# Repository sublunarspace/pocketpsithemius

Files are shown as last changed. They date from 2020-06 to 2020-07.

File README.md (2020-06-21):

# Pocket Psithemius

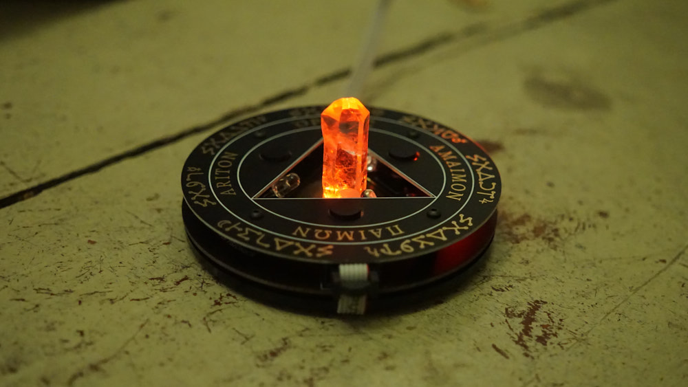
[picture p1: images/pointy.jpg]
Psithemius


The Psithemius is a psionic device for spirit conjuration and magical manifestation.

Its basic architecture consists of printed circuit boards hosting concentric circles with magical names and symbols and a triangle with a spiral shaped transmitter in its center. The design is based on a system attributed to the German abbot and polymath Johannes Trithemius who lived around the end of the 15th century and developed methods for communing with transdimensional entities.

For the Psithemius device to work properly, a quartz crystal is needed. The device emits light and an electromagnetic field around and into this quartz crystal set in the center of the triangle that acts as a focal point and spirit medium.

The Psithemius device utilizes principles from Psionics to detect and electrically amplify intent in the form of magical sigils or radionic rates sent to it. The goal is to charge the crystal with energies resonating with the nature of an entity and act as a beacon of condensed intent to attract them to the ritual space.

## Get the Psithemius

You can [purchase a Pocket Psithemius directly from Sublunar Psionics](mailto:info@sublunar.space). It comes in three different versions. All versions come with a USB power cable and a small carry bag.

* Fully assembled device (EUR 99.00)
* DIY kit incl. PCBs and all components (EUR 69.00)
* PCBs only - without components (EUR 49.00)

[Operator Manual](MANUAL.md)

[Assembly Instructions](hardware/ASSEMBLY.md)

[BOM List of Components](hardware/BOM.csv) / [PDF](hardware/BOM.pdf)

[Component Images](hardware/parts_preview.pdf)

## Code the Psithemius

Modify the firmware that runs the Psithemius or write your own from scratch. It's all fully Arduino compatible.

[Arduino IDE Firmware](firmware/)

## Fork the Psithemius

You can download the KiCAD project files (schematic, circuit board design, gerber files) and manufacture your own Psithemius or modify it

[KiCAD Files](hardware/)

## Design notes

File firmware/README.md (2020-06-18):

# Pocket Psithemius

Firmware for the Pocket Psithemius device.

## Installation

* Set up an Arduino as ISP programmer following [this tutorial](https://www.arduino.cc/en/Tutorial/ArduinoISP) or use any other ICSP compatible programmer.
* The firmware depends on the [OneButton library](https://github.com/mathertel/OneButton) which you need to install with the IDE's Library Manager
* Connect the Pocket Psithemius via ICSP to the programmer.

### IDE Tools Settings

* Board: Attiny24/44/84
* Chip: Attiny84
* Clock: 8MHz (internal)
* B.O.D. Level: B.O.D. Disabled
* Save EEPROM: EEPROM retained
* Pin Mapping: clockwise
* LTO: Enabled
* millis()/micros(): Enabled

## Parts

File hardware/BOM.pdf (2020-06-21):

Reference | Quantity Value | Description | Manufacturer | Part Number | Digikey Number | Mouser Number
C1 | 1 | 1uF | Capacitor | Vishay | K105Z20Y5VF5TH5 BC1168CT-ND | 594-K105Z20Y5VF5TH5
C2, C5, C10 | 3 | 0.1uF | Capacitor | Vishay | K104K15X7RF5TH5 BC1101CT-ND | 594-K104K15X7RF5TH5
C3 | 1 | 0.1uF/35V | Pol. Capacitor | Nishicon | UMA1H0R1MCD2TP 493-10420-3-ND | N/A
C4 | 1 | 10uF/10V | Pol. Capacitor | Vishay | USV1C100MFD | 493-16020-ND | 647-USV1C100MFD1TE
C6, C11 | 2 | 220uF/16V | Pol. Capacitor | Nishicon | USR1C221MDD | 493-15996-ND | 647-USR1C221MDD
D1 | 1 | LED_RGBA | RGB LED | Würth Elektronik | 156125M173000 | 732-11426-1-ND | 710-156125M173000
D2, D3, D4 | 3 | UV | UV LED | Nichia | VAOL-5GUV8T4 | VAOL-5GUV8T4-ND 593-VAOL5GUV8T4
H1, H2, H3, H4 | 4 | M2.5/9mm | Distance Bolt | Würth Elektronik | 960090021 | 732-12693-ND | N/A
H1, H2, H3, H4 | 4 | M2.5/7mm | Distance Bolt | Würth Elektronik | 960070021 | 732-12683-ND | N/A
H1, H2, H3, H4 | 4 | M2.5/25mm | Screw | N/A | 10.9-7380-M2.5x20 | N/A | N/A
H1, H2, H3, H4 | 4 | M2.5 | Washer | N/A | ST-M2.5-125 | N/A | N/A
H1, H2, H3, H4 | 4 | M2.5 | Nut | N/A | ST-M2.5-934 | N/A | N/A
J1 | 1 | 3.5mm | Audio Mini Jack | CUI Devices | SJ1-3523N | CP1-3523N-ND | 490-SJ1-3523N
J2 | 1 | PJ-051AH | Barrel Jack | CUI Devices | PJ-051AH | CP-051AH-ND | 490-PJ-051AH
J3 | 1 | 7761 | M2.5 / Earth | Keystone Electronics | 7761 | 36-7761-ND | 534-7761
J4 | 1 | AVR-ISP-6 | Flat Cable Socket Würth Elektronik | 61200621721 | 732-5404-ND | 710-61200621721
J5 | 1 | BAT | Battery Socket | JST | S4B-PH-K-S(LF)(SN) 455-1721-ND | N/A
R1, R2, R3, R4, R7 | 5 | 10K | Resistor | Stackpole Electronics CF18JT10K0 | CF18JT10K0CT-ND N/A
R5 | 1 | 10 | Resistor | Stackpole Electronics CF18JT10R0 | CF18JT10R0CT-ND N/A
R6, R11, R15 | 3 | 180 | Resistor | Stackpole Electronics CF18JT180R | CF18JT180RCT-ND N/A
R8, R9, R10 | 3 | 680 | Resistor | Stackpole Electronics CF18JT680R | CF18JT680RCT-ND N/A
R12, R13, R14 | 3 | 330 | Resistor | Stackpole Electronics CF18JT330R | CF18JT330RCT-ND N/A
R16 | 1 | 4 | Resistor | Stackpole Electronics WW1AFT4R00 | WW1AFT4R00-ND | N/A
SW1, SW2, SW3 | 3 | B3F-4050 | Switch | Omron | B3F-4050 | SW413-ND | 653-B3F-4050
SW1, SW2, SW3 | 3 | | Switch Cap | Omron | B32-1610 | SW847-ND | 653-B32-1610
SW4 | 1 | JS202011AQN Switch | C & K | JS202011AQN | 401-2000-ND | 611-JS202011AQN
U1 | 1 | ATtiny84A-PU Microcontroller | Microchip Technology ATTINY84-20PU | ATTINY84-20PU-ND 556-ATTINY84-20PU
U2 | 1 | TLP222A | Optical Relay | Toshiba | TLP222A-2(F) | TLP222A-2F-ND | 757-TLP222A-2(F)
U3 | 1 | TLP4227GF | Optical Relay | Toshiba | TLP4227GF | TLP4227GF-ND | 757-TLP4227G(F)
U4 | 1 | LM386 | Op-Amp | Texas Instruments | LM386MX-1/NOPB | 296-44414-5-ND | 926-LM386MX-1/NOPB
VR1 | 1 | 3352T-1-103LF Var. Resistor | Bourns | 3352T-1-103LF | 3352T-103LF-ND | 652-3352T-1-103LF

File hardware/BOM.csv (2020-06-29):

Reference | Quantity | Value | Description | Datasheet | Manufacturer | Part Number | Digikey Number | Mouser Number
C1 | 1 | 1uF | Capacitor | http://www.vishay.com/docs/45171/kseries.pdf | Vishay | K105Z20Y5VF5TH5 | BC1168CT-ND | 594-K105Z20Y5VF5TH5
C2, C5, C10 | 3 | 0.1uF | Capacitor | http://www.vishay.com/docs/45171/kseries.pdf | Vishay | K104K15X7RF5TH5 | BC1101CT-ND | 594-K104K15X7RF5TH5
C3 | 1 | 0.1uF/35V | Pol. Capacitor | https://www.nichicon.co.jp/english/products/pdfs/e-uma.pdf | Nishicon | UMA1H0R1MCD2TP | 493-10420-3-ND | N/A
C4 | 1 | 10uF/10V | Pol. Capacitor | http://nichicon-us.com/english/products/pdfs/e-usv.pdf | Vishay | USV1C100MFD | 493-16020-ND | 647-USV1C100MFD1TE
C6, C11 | 2 | 220uF/16V | Pol. Capacitor | http://nichicon-us.com/english/products/pdfs/e-usa_usr.pdf | Nishicon | USR1C221MDD | 493-15996-ND | 647-USR1C221MDD
D1 | 1 | LED_RGBA | RGB LED | https://katalog.we-online.de/led/datasheet/156125M173000.pdf | Würth Elektronik | 156125M173000 | 732-11426-1-ND | 710-156125M173000
D2, D3, D4 | 3 | UV | UV LED | http://static.vcclite.com/pdf/VAOL-5GUV8T4-LED-5mm-UV.pdf | Nichia | VAOL-5GUV8T4 | VAOL-5GUV8T4-ND | 593-VAOL5GUV8T4
H1, H2, H3, H4 | 4 | M2.5/9mm | Distance Bolt | https://katalog.we-online.de/em/datasheet/960xxxxxx.pdf | Würth Elektronik | 960090021 | 732-12693-ND | N/A
H1, H2, H3, H4 | 4 | M2.5/7mm | Distance Bolt | https://katalog.we-online.de/em/datasheet/960xxxxxx.pdf | Würth Elektronik | 960070021 | 732-12683-ND | N/A
H1, H2, H3, H4 | 4 | M2.5/25mm | Screw | N/A | N/A | 10.9-7380-M2.5x20 | N/A | N/A
H1, H2, H3, H4 | 4 | M2.5 | Washer | N/A | N/A | ST-M2.5-125 | N/A | N/A
H1, H2, H3, H4 | 4 | M2.5 | Nut | N/A | N/A | ST-M2.5-934 | N/A | N/A
J1 | 1 | 3.5mm | Audio Mini Jack | https://www.cuidevices.com/product/resource/digikeypdf/sj1-352xn.pdf | CUI Devices | SJ1-3523N | CP1-3523N-ND | 490-SJ1-3523N
J2 | 1 | PJ-051AH | Barrel Jack | https://www.cuidevices.com/product/resource/pj-051ah.pdf | CUI Devices | PJ-051AH | CP-051AH-ND | 490-PJ-051AH
J3 | 1 | 7761 | M2.5 / Earth | http://keyelco.com/userAssets/file/M65p69.pdf | Keystone Electronics | 7761 | 36-7761-ND | 534-7761
J4 | 1 | AVR-ISP-6 | Flat Cable Socket | https://katalog.we-online.de/em/datasheet/6120xx21721.pdf | Würth Elektronik | 61200621721 | 732-5404-ND | 710-61200621721
J5 | 1 | BAT | Battery Socket | http://www.jst-mfg.com/product/pdf/eng/ePH.pdf | JST | S4B-PH-K-S(LF)(SN) | 455-1721-ND | N/A
R1, R2, R3, R4, R7 | 5 | 10K | Resistor | https://www.seielect.com/catalog/sei-cf_cfm.pdf | Stackpole Electronics | CF18JT10K0 | CF18JT10K0CT-ND | N/A
R5 | 1 | 10 | Resistor | https://www.seielect.com/catalog/sei-cf_cfm.pdf | Stackpole Electronics | CF18JT10R0 | CF18JT10R0CT-ND | N/A
R6, R11, R15 | 3 | 180 | Resistor | https://www.seielect.com/catalog/sei-cf_cfm.pdf | Stackpole Electronics | CF18JT180R | CF18JT180RCT-ND | N/A
R8, R9, R10 | 3 | 680 | Resistor | https://www.seielect.com/catalog/sei-cf_cfm.pdf | Stackpole Electronics | CF18JT680R | CF18JT680RCT-ND | N/A
R12, R13, R14 | 3 | 330 | Resistor | https://www.seielect.com/catalog/sei-cf_cfm.pdf | Stackpole Electronics | CF18JT330R | CF18JT330RCT-ND | N/A
R16 | 1 | 4 | Resistor | https://www.seielect.com/catalog/sei-cf_cfm.pdf | Stackpole Electronics | WW1AFT4R00 | WW1AFT4R00-ND | N/A
SW1, SW2, SW3 | 3 | B3F-4050 | Switch | https://omronfs.omron.com/en_US/ecb/products/pdf/en-b3f.pdf | Omron | B3F-4050 | SW413-ND | 653-B3F-4050
SW1, SW2, SW3 | 3 |  | Switch Cap | https://omronfs.omron.com/en_US/ecb/products/pdf/en-b32.pdf | Omron | B32-1610 | SW847-ND | 653-B32-1610
S1 | 1 | JS202011AQN | Switch | https://www.ckswitches.com/media/1422/js.pdf | C & K | JS202011AQN | 401-2000-ND | 611-JS202011AQN
U1 | 1 | ATtiny84A-PU | Microcontroller | http://ww1.microchip.com/downloads/en/DeviceDoc/doc8183.pdf | Microchip Technology | ATTINY84-20PU | ATTINY84-20PU-ND | 556-ATTINY84-20PU
U2 | 1 | TLP222A | Optical Relay | https://toshiba.semicon-storage.com/info/docget.jsp?did=17036&prodName=TLP222A | Toshiba | TLP222A-2(F) | TLP222A-2F-ND | 757-TLP222A-2(F)
U3 | 1 | TLP4227GF | Optical Relay | http://toshiba.semicon-storage.com/info/docget.jsp?did=17079&prodName=TLP4227G-2 | Toshiba | TLP4227GF | TLP4227GF-ND | 757-TLP4227G(F)
U4 | 1 | LM386 | Op-Amp | http://www.ti.com/lit/ds/symlink/lm386.pdf | Texas Instruments | LM386MX-1/NOPB | 296-44414-5-ND | 926-LM386MX-1/NOPB
VR1 | 1 | 3352T-1-103LF | Var. Resistor | https://www.bourns.com/docs/Product-Datasheets/3352.pdf | Bourns | 3352T-1-103LF | 3352T-103LF-ND | 652-3352T-1-103LF

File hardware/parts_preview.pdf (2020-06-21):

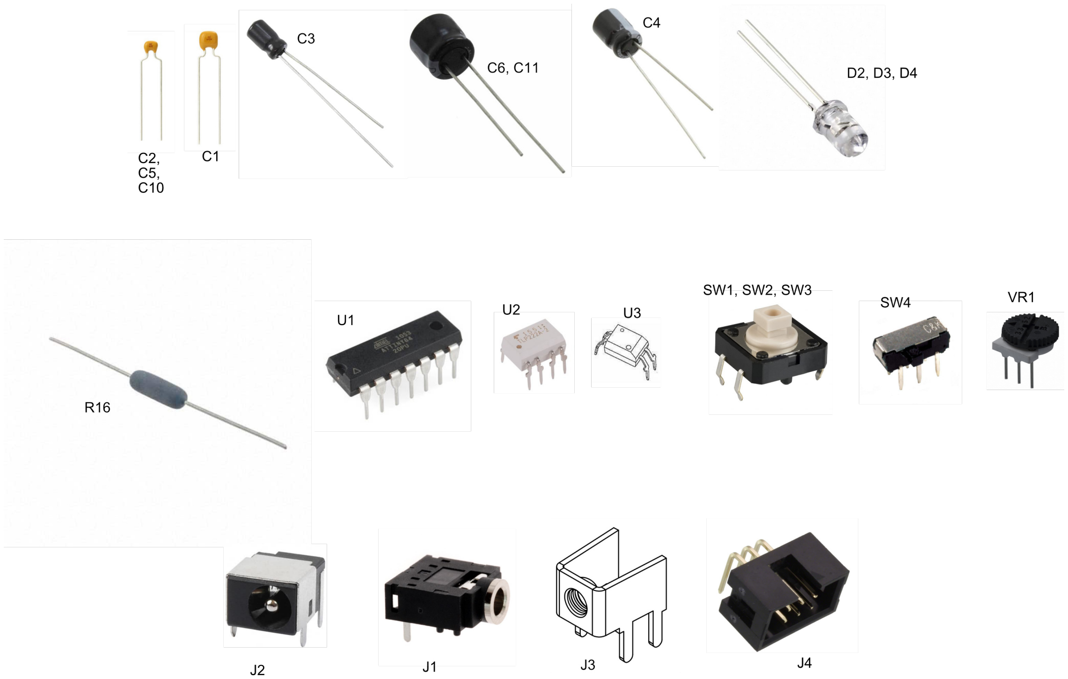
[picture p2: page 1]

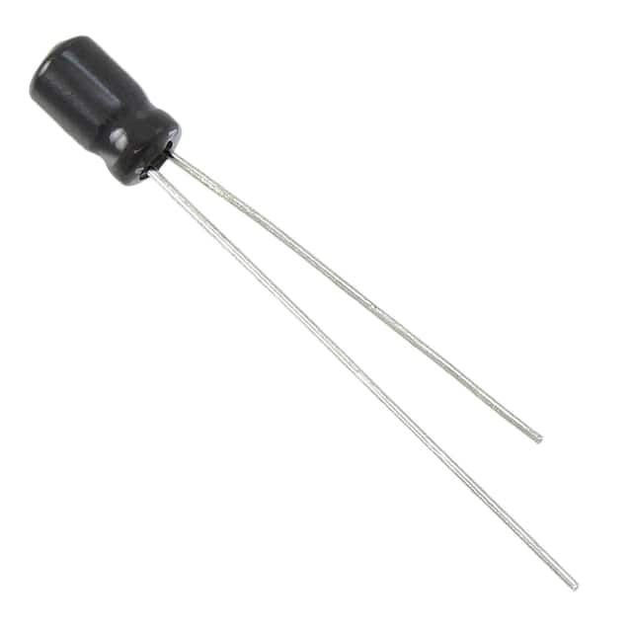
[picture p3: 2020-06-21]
hardware/components/UMA1H0R1MCD2TP.jpg

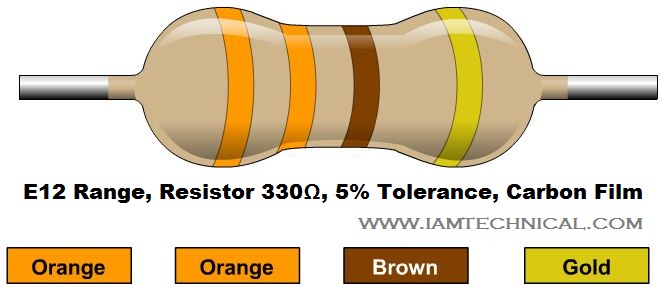
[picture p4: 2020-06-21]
hardware/components/330-ohm-resistor-color-code.jpg

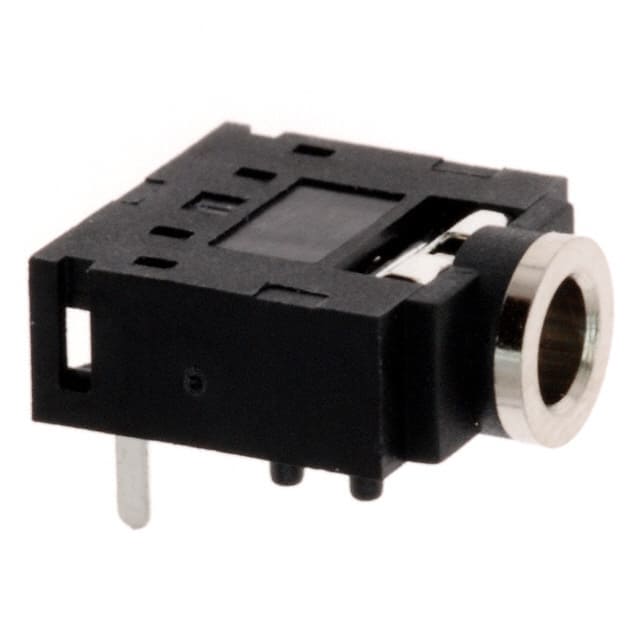
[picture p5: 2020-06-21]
hardware/components/SJ1-3523N.jpg

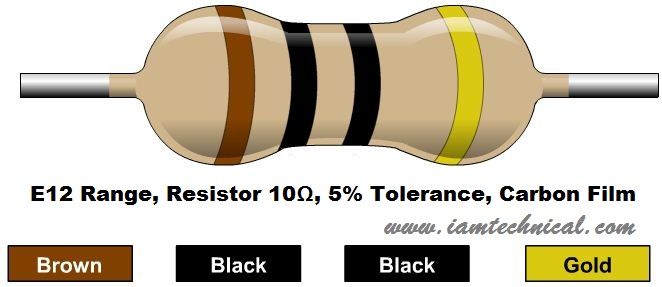
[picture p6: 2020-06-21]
hardware/components/10-ohm-resistor-color-code.jpg

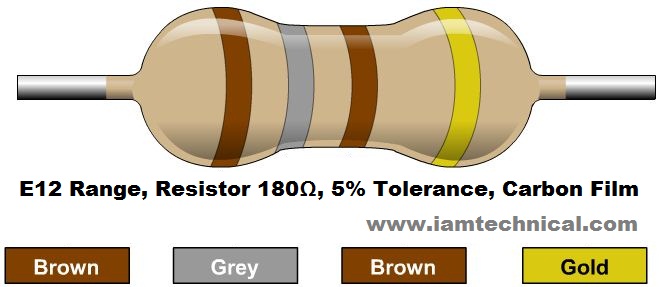
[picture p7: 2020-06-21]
hardware/components/180-ohm-resistor-color-code.jpg

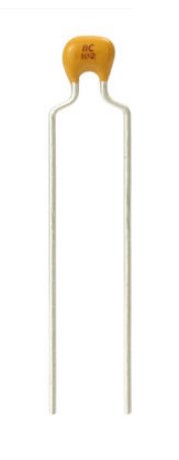
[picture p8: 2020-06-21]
hardware/components/K104K15X7RF5TH5.jpg

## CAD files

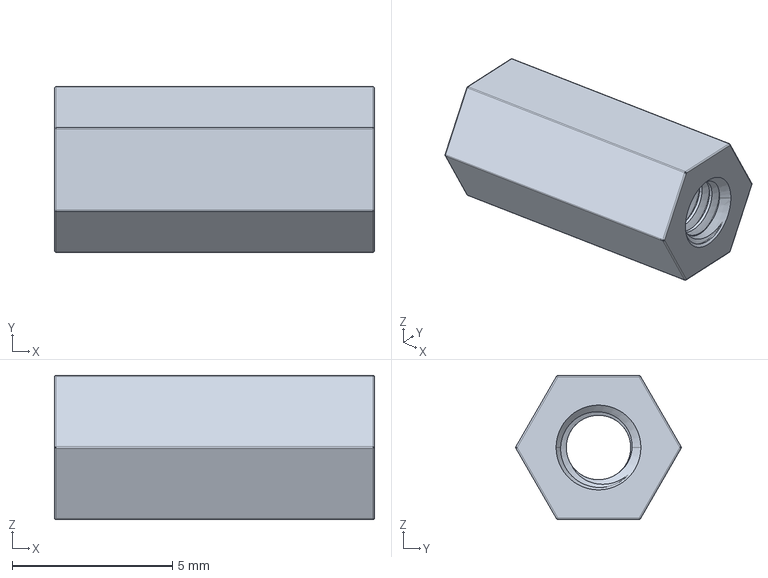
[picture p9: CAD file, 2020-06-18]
hardware/psithemius/parts/RAF_M1257-2545-AL.step
10.0 x 5.18 x 4.50 mm

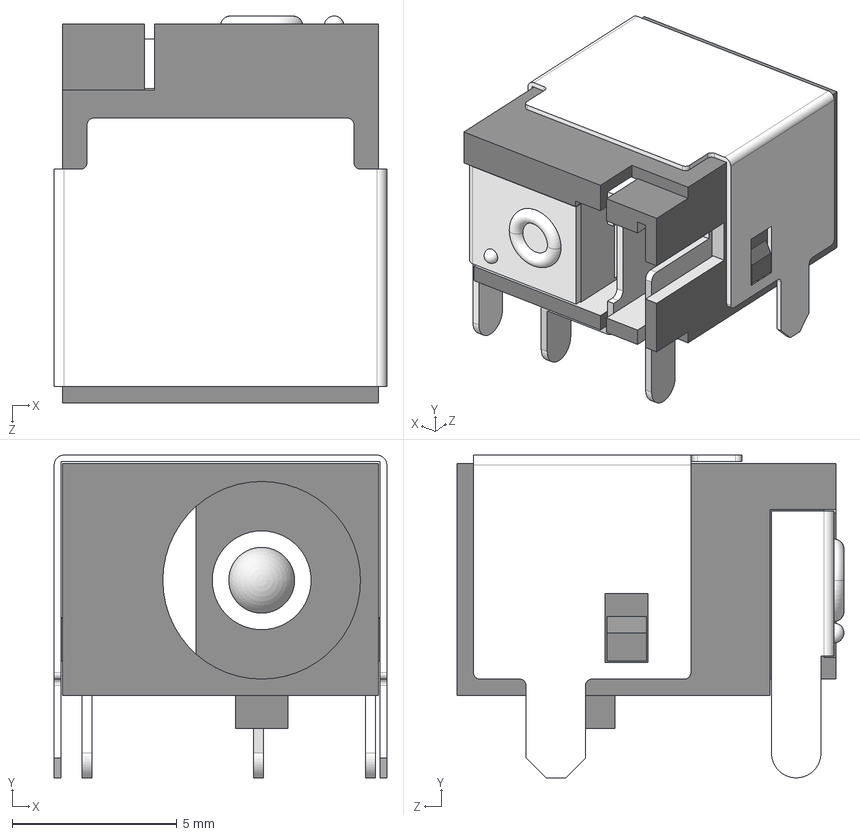
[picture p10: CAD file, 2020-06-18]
hardware/psithemius/parts/CUI_DEVICES_PJ-051AH.step
10.1 x 9.80 x 11.8 mm

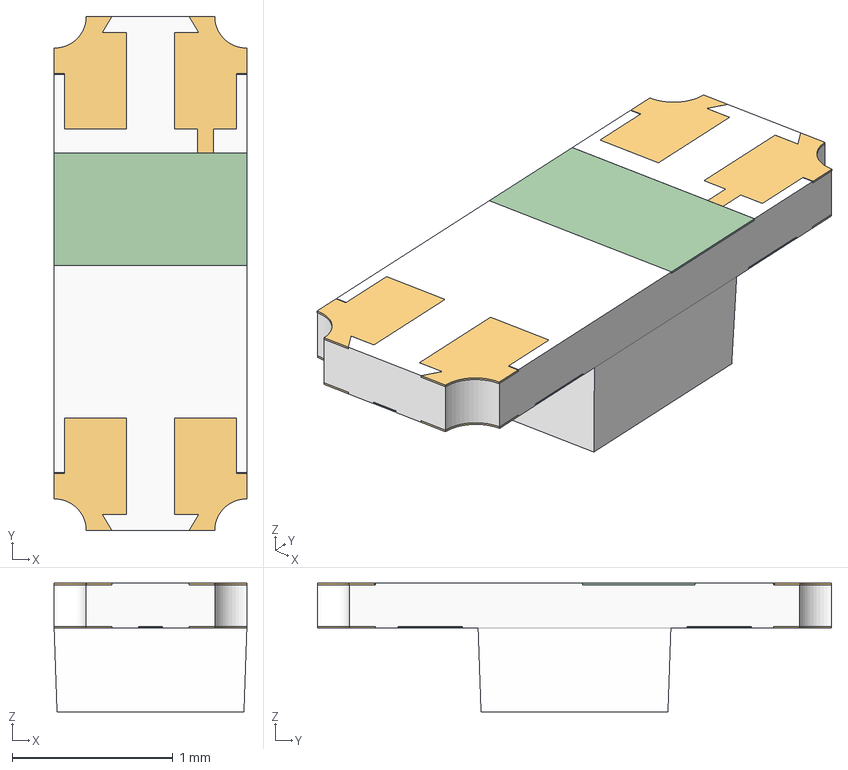
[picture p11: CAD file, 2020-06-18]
hardware/psithemius/parts/WurthElektronik_156125M173000.step
1.20 x 3.20 x 0.8 mm
Pins_top x 5
Pins_Bottom x 5

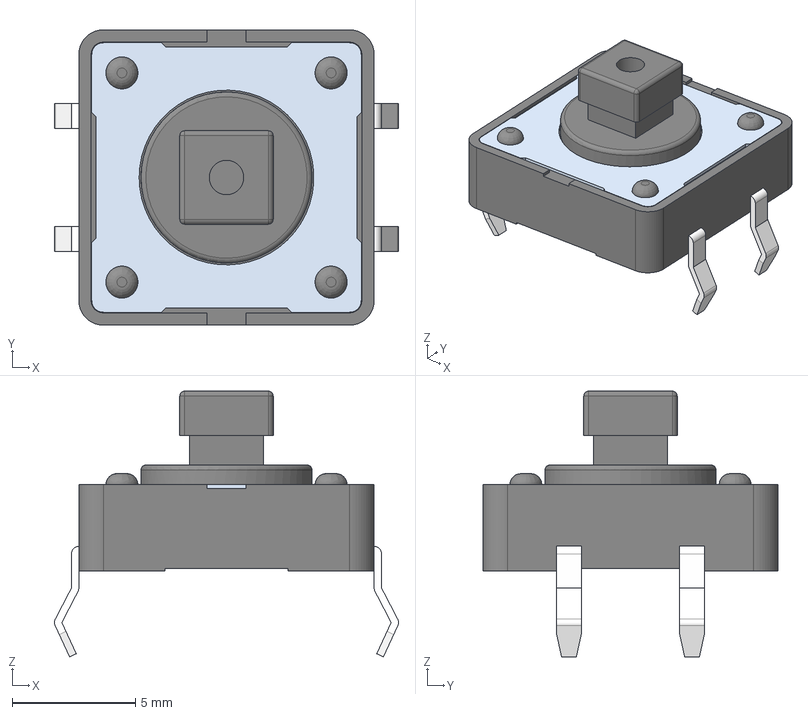
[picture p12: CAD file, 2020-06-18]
hardware/psithemius/parts/SW_Tactile_SPST-NO_Omron_B3F-40xx.step
14.0 x 12.0 x 10.8 mm

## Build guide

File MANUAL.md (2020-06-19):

# Pocket Psithemius Operator Manual

- [Pocket Psithemius Operator Manual](#pocket-psithemius-operator-manual)
  * [Caution](#caution)
  * [Setup](#setup)
  * [Power](#power)
  * [Button Functions](#button-functions)
    + [Button A](#button-a)
    + [Button B](#button-b)
    + [Button C](#button-c)
  * [Modes of Operation](#modes-of-operation)
    + [Primary Modes](#primary-modes)
    + [Secondary Modes](#secondary-modes)
  * [Detailed Primary Operations](#detailed-primary-operations)
    + [I. Trithemian Table of Practice](#i-trithemian-table-of-practice)
    + [II. Crystal Programming](#ii-crystal-programming)
      - [1. Clearing the Crystal](#1-clearing-the-crystal)
      - [2. Programming the Crystal](#2-programming-the-crystal)
      - [3a. Audio Frequency Imprint](#3a-audio-frequency-imprint)
      - [3b. Signal Generator Imprint](#3b-signal-generator-imprint)
      - [3c. Psionic Imprint](#3c-psionic-imprint)
      - [3d. Seal Imprint](#3d-seal-imprint)
      - [4. Ritual Recommendations](#4-ritual-recommendations)
  * [Detailed Secondary Operations](#detailed-secondary-operations)
    + [I. Frequency Resonator](#i-frequency-resonator)
    + [II. Amplified Radionic Transmitter](#ii-amplified-radionic-transmitter)
    + [III. Fluid Condenser Mirror Charger](#iii-fluid-condenser-mirror-charger)
    + [IV. Wishing Machine / Sigil Activator](#iv-wishing-machine---sigil-activator)

## Caution

* The device has three built in 385nm UV-A LEDs that are quite intense (120mW) and can be harmful to eyes and skin.
* Follow the instructions carefully!
* Do Not look directly into UV light. This can be harmful to the human body especially to the eyes and skin, even for brief period due to the intense UV light.
* If viewing the UV light is necessary, please use UV filtered glasses to avoid damage by the UV light.
* Avoid direct eye and skin exposure to the UV light.
* *KEEP CHILDREN OUT OF REACH*.

## Setup

Place the Psithemius in front of you with the word OPIENC and the small hexagram or "star of David" symbol ✡ in the triangle pointing away from you.

For magical operations it is advised to sit in front of the Psithemius facing East. For radionic operations it is advised to face North instead.

## Power

Your Pocket Psithemius comes with a 0.5m long USB-A to 5.5 mm/2.1 mm 5V DC Barrel Jack power cable. Plug the Barrel connector end of the cable into the Barrel socket at the rear of the device and connect the USB-A plug into a USB socket or 5V DC USB Power Adapter such as the one that came with your mobile phone. Alternatively you may also plug it into any portable USB Power Bank battery pack.

Power the device on by flicking the tiny ON/OFF switch to the left. It is located at the rear lefthand side next to the power connector.

## Button Functions

The device has three buttons: A on the left side of the triangle, B on the right side, and C in front of the triangle towards you. Please read what the buttons do. In the detailed sections below you will learn how to apply these functions properly.

### Button A

* Momentarily pressing button A turns an LED in the center of the triangle on.

* Subsequent presses of button A allow you to cycle through a selection of 9 colors that follow classic planetary correspondences and then turns the LED off again.

* Pressing and holding button A for more than a second and then releasing it activates a randomized display of colors in random frequencies. Pressing and holding button A again deactivates this mode again.

### Button B

* Momentarily pressing button B triggers a countdown of 5 second indicated by a blinking blue light. After the countdown is over the three UV-LEDs turn on and remain on for 60 seconds, then turn off.

* Any momentary press of button B while the UV-LEDs are on will immediately turn them off.

* Pressing and holding button B for more than a second triggers a countdown of 5 second indicated by a blinking blue light. The last blink is followed by 5 more rapid blinks. After the countdown is over the three UV-LEDs turn on and remain on. All buttons are deactivated in this mode. The device needs to be completely turned off in order to re-activate all buttons.

### Button C

* Momentarily pressing button C makes the LED blink green twice and turn an internal amplification circuit on. 

* A subsequent press of button C makes the LED blink red twice and turn the internal amplification circuit off.

## Modes of Operation

### Primary Modes

The Psithemius has been designed to provide functionality for different modes of operation. Its main function is to serve as a so-called [Trithemian Table of Practice](#i-trithemian-table-of-practice) with a "triangle of manifestation" for conjurations following the established protocol of such practice laid out in the so-called "Trithemian" tradition of "drawing spirits into crystals".

In addition the device incorporates electronic functions to improve this mode of use by enabling the operator to clear a quartz crystal before and after such operation and to [prime it with colors and resonance](#ii-crystal-programming) according to classic planetary correspondences.

### Secondary Modes

Due to the combination of functions built into the Psithemius it also allows for additional use cases:

* [Frequency Resonator](#i-frequency-resonator)
* [Amplified Radionic Transmitter](#ii-amplified-radionic-transmitter)
* [Fluid Condenser Mirror Charger](#iii-fluid-condenser-mirror-charger)
* [Wishing Machine / Sigil Activator](#iv-wishing-machine---sigil-activator)

## Detailed Primary Operations

### I. Trithemian Table of Practice

Unpowered, the Psithemius can be used as a portable classic Trithemian table of practice. The overall design is based on this magical tool. 

The circular "table" features two concentric circles with magical names and characters: 

The outer ring features the names of the seven planetary archangels Michael (Sun), Haniel (Venus), Raphael (Mercury), Gabriel (Moon), Qaphziel (Saturn), Sachiel (Jupiter), and Samael (Mars). The names are written in their original Hebrew spelling set in a magical typeface called "Celestial script" found in Heinrich Cornelius Agrippa von Nettesheim's "Third Book of Occult Philosophy". Assuming the rear end of the device resembles the Eastern cardinal direction they are placed around the circle in the classic "Chaldean" order from Saturn to the Moon and aligning the sun towards the East.

The inner ring features the names of the four Elemental or Cardinal Kings Oriens (East), Paimon (West), Ariton (North), Amaimon (South), again according to their directions assuming the rear end of the device points East. For any kind of operation, position the Psithemius in a way that the Cardinal Kings names point into the correct cardinal directions.

In the center of the circles is a so-called "triangle of manifestation".

A precise descriptio of its design elements have been given by Frater Rufus Opus in some of his course material on the subject:

>The Table of Practice is a symbol of the cosmos. [...] The outermost circle represents the Seven Heavens and the Intelligences therein. They are the governors of the spheres, and their presence helps ensure you get the spirit you’re looking for when you perform your conjuration. The Elemental Kings provide the gate to the material realm, so the spirits can influence your life materially, if necessary, but they also make sure that any spirit you call up of a terrestrial nature won’t go ballistic and eat your soul, leaving you dead by dawn. These two circles together represent the meeting of the Heavens and the Earth in your temple space. [...] Taken altogether, the Table of Practice represents our relationship with the Seven Governors, the Four Elemental Kings, and the Process of Manifestation. It is designed to provide the place where a spirit can manifest, and to give us a shared space between the Heavens and the Earth in which we can work together to accomplish the things we have to do.

The Psithemius is a mere tool to be used in a ritual context of the pracice discussed here. A detailed manual for this system of conjuration exceeds the purpose of this manual by far. If you want to learn more on the subject, please consult [Frater Rufus Opus book "Seven Spheres"](https://www.goodreads.com/book/show/23644473-seven-spheres) or dive into Polyphanes' extensive treatment of the subject in his [free ebook](http://digitalambler.files.wordpress.com/2019/10/trithemius.pdf).

### II. Crystal Programming

Part of the work briefly touched in part I is the accumulation of materia magica resonating with the planetary forces of the transdimensional entities the operator wishes to conjure. Traditionally this is achieved by placing precious stones, metals, herbs, symbols, or other material onto the altar used for the operation, following the principle of like attracting alike. 

The Psithemius offers an innovative new way of enhancing this method by priming the quartz crystal that is usually placed into the center of the Triangle of Manifestation. Prior to a conjuration the operator can clear the crystal of all previously imprinted energetic patterns and then charge it with a set of resonances auspiciously adjusted to the desired planetary correspondences needed for the operation.

#### 1. Clearing the Crystal

1. Place the quartz crystal to be used in the operation into the center of the triangle

2. Momentarily press button B to start the countdown for the UV-LEDs to turn on.

3. While the countdown is running, move away from the device or put on some protective gear for your eyes and skin.

4. After the 5 second countdown, the UV-LEDs will turn on and immerse the crystal in strong ultraviolet light

*CAUTION:*

* The device has three built in 385nm UV-A LEDs that are quite intense (120mW) and can be harmful to eyes and skin.
* Follow the instructions carefully!
* Do Not look directly into UV light. This can be harmful to the human body especially to the eyes and skin, even for brief period due to the intense UV light.
* If viewing the UV light is necessary, please use UV filtered glasses to avoid damage by the UV light.
* Avoid direct eye and skin exposure to the UV light.
* *KEEP CHILDREN OUT OF REACH*.

5. After 60 seconds the UV-LEDs turn off and it is safe for you to operate the device again. The crystal should be cleared now.

#### 2. Programming the Crystal

1. Take the crystal out of the triangle.

2. Using short presses of button A, select a color that corresponds with the planetary energy of your planned operation. Here is a list of the color cycle and possible correspondences:

* white (Moon)
* orange (Mercury)
* green (Venus)
* yellow (Sun)
* red (Mars)
* celestial blue (Jupiter)
* purple (Jupiter)
* indigo (Saturn)
* grey (Saturn)
* off (Saturn)

#### 3a. Audio Frequency Imprint

1. Plug an audio frequency generator (e.g. your Android phone running the app "Signal Generator") into the 3.5mm 1/8" mini jack at the rear end of the Psithemius using a male to male 3.5mm 1/8" mini jack cable. Select a frequency that corresponds with the planetary energy of your planned operation.

2. Press button C to activate the internal amplification circuit. The audio signal is turned into an electromagnetic field radiating out of the clockwise spiral in the center of the triangle. 

3. Use the thumb wheel at the front left of the device to adjust the amplification gain. Turn it to the left (clockwise) for a lesser (down to 20fold) amplification of the signal. Or turn it to the right (counterclockwise) for a stronger (up to 200fold).

4. Place the crystal back into the center of the triangle and immerse it with the selected light and frequencies.

#### 3b. Signal Generator Imprint

1. Plug a frequency generator such as the Spooky2, PicBerry, FG085 into the 3.5mm 1/8" mini jack at the rear end of the Psithemius using a BNC to male 3.5mm 1/8" mini jack adapter cable. Since signal generators usually output a voltage up to 20V, no amplification is needed. DO NOT TURN THE INTERNAL AMPLIFICATION ON.

2. Place the crystal back into the center of the triangle and immerse it with the selected light and frequencies.

#### 3c. Psionic Imprint

1. Instead of a frequency signal, you may also plug any psionic or radionic device into the into the 3.5mm 1/8" mini jack at the rear end of the Psithemius using a proper adapter cable.

2. If the psionic or radionic device outputs and unamplified signal, you may amplify it by a momentary press button C to activate the internal amplification circuit. The radionic signal is radiating out of the clockwise spiral in the center of the triangle. 

3. Use the thumb wheel at the front left of the device to adjust the amplification gain. Turn it to the left (clockwise) for a lesser (down to 20fold) amplification of the signal. Or turn it to the right (counterclockwise) for a stronger (up to 200fold).

4. Place the crystal back into the center of the triangle and immerse it with the selected light and psionic information.

#### 3d. Seal Imprint

1. If you have the Sublunar Psionics Ingress Plate with Universal Lamen cover disk, you can also imprint the crystal with the focused energies of the entity to be conjured.

2. Place a slip of optionally consecrated paper or parchment under the Universal Lamen cover disk and draw the seal onto the paper revealed by the hexagon.

3. Cut out the seal so it fits onto the Ingress Plate without any overlap.

4. Place the Universal Lamen cover disk on top of it so the seal is visible in the center of the hexagram and all pentagrams are facing away from you

5. Connect the Ingress Plate into the 3.5mm 1/8" mini jack at the rear end of the Psithemius using a male to male 3.5mm 1/8" mini jack cable.

6. Press button C to activate the internal amplification circuit. The psionic signal coming from the Ingress Plate is turned into an electromagnetic field radiating out of the clockwise spiral in the center of the triangle. 

7. Use the thumb wheel at the front left of the device to adjust the amplification gain. Turn it to the left (clockwise) for a lesser (down to 20fold) amplification of the signal. Or turn it to the right (counterclockwise) for a stronger (up to 200fold).

8. Place the crystal back into the center of the triangle and immerse it with the selected light and psionic imprint of the seal.

#### 4. Ritual Recommendations

Once the priming of the crystal has been finished, the operation can begin. It is recommended but not necessary to turn the color LED and amplification circuits off for the duration of the operation as electromagnetic radiation may interfere with the conjuration.

If you have the Ingress Plate + Universal Lamen with a seal connected to the Psithemius, leave them connected as the energies of the seal will still flow into the Triangle of Manifestation even when unpowered.

If the operation does not follow immediately after programming the crystal, make sure to store the crystal in a dark enclosure out of proximity of embodied living beings.

If something in the ritual goes awry you may press button B at any time as a "kill switch" to immerse the crystal in ultraviolet light and abruptly end the operation. In such a case make sure to also banish ritually.

*CAUTION:*

* The device has three built in 385nm UV-A LEDs that are quite intense (120mW) and can be harmful to eyes and skin.
* Follow the instructions carefully!
* Do Not look directly into UV light. This can be harmful to the human body especially to the eyes and skin, even for brief period due to the intense UV light.
* If viewing the UV light is necessary, please use UV filtered glasses to avoid damage by the UV light.
* Avoid direct eye and skin exposure to the UV light.
* *KEEP CHILDREN OUT OF REACH*.

## Detailed Secondary Operations

### I. Frequency Resonator

1. To immerse yourself in healing sound frequencies, such as the Schumann Resonance of 7.8Hz plug an audio frequency generator (e.g. your Android phone running the app "Signal Generator") into the 3.5mm 1/8" mini jack at the rear end of the Psithemius using a male to male 3.5mm 1/8" mini jack cable. Select a desired frequency.

2. Press button C to activate the internal amplification circuit. The audio signal is turned into an electromagnetic field radiating out of the clockwise spiral in the center of the triangle. 

3. Use the thumb wheel at the front left of the device to adjust the amplification gain. Turn it to the left (clockwise) for a lesser (down to 20fold) amplification of the signal. Or turn it to the right (counterclockwise) for a stronger (up to 200fold).

4. Make sure no crystal is placed in the center of the triangle blocking the free flow of the signal into the room.

### II. Amplified Radionic Transmitter

1. If you have an unpowered psionic or radionic device and would like to boost its output signal, plug its output into the 3.5mm 1/8" mini jack at the rear end of the Psithemius using a proper adapter cable.

2. Optionally place a single pointed quartz crystal into the center of the triangle for improved amplification. Press button B to initiate a clearing routine of the crystal. Keep away from the UVA light and come back when the UV-LEDs have turned off after 60 seconds.

*CAUTION:*

* The device has three built in 385nm UV-A LEDs that are quite intense (120mW) and can be harmful to eyes and skin.
* Follow the instructions carefully!
* Do Not look directly into UV light. This can be harmful to the human body especially to the eyes and skin, even for brief period due to the intense UV light.
* If viewing the UV light is necessary, please use UV filtered glasses to avoid damage by the UV light.
* Avoid direct eye and skin exposure to the UV light.
* *KEEP CHILDREN OUT OF REACH*.

3. If the connected psionic or radionic device is not grounded to earth, it is recommended to connect a wire to the M2.5 tap hole earth connector located in the middle between the Barrel jack and 3.5mm 1/8" at the rear end of the Psithemius. The other end of the wire should be physically connected to the earth, either by using a wire and a pole or by connecting it to the pipe of a radiator.

4. Press button C to activate the internal amplification circuit. The amplified psionic signal is radiating out of the clockwise spiral in the center of the triangle. 

5. Use the thumb wheel at the front left of the device to adjust the amplification gain. Turn it to the left (clockwise) for a lesser (down to 20fold) amplification of the signal. Or turn it to the right (counterclockwise) for a stronger (up to 200fold).

6. Any rate dialed into the connected psionic or radionic device will transmit into the aether amplified by the Psithemius.

### III. Fluid Condenser Mirror Charger

If you have a Psychurgical Mirror consisting of fluid condenser material, such as the one invented by Lukáš Loužecký and [distributed by Czech Hermetics](http://czechhermetics.com/the-almost-forgotten-art-of-psychurgical-mirrors/), you are aware that they need to be charged with either sunlight for 5 minutes or ultraviolet light for around an hour prior to a scrying operation. The Psithemius has a special function to achieve that:

1. Press and hold button B for more than a second and trigger the countdown for activating the UV-LEDs.

2. During the countdown carefully place the psychurgic mirror on the Psithemius.

3. After the countdown is over, the UV lights turn and remain on and all buttons are deactivated so they are not accidentally triggered by the psychurgic mirror resting on them.

*CAUTION:*

* The device has three built in 385nm UV-A LEDs that are quite intense (120mW) and can be harmful to eyes and skin.
* Follow the instructions carefully!
* Do Not look directly into UV light. This can be harmful to the human body especially to the eyes and skin, even for brief period due to the intense UV light.
* If viewing the UV light is necessary, please use UV filtered glasses to avoid damage by the UV light.
* Avoid direct eye and skin exposure to the UV light.
* *KEEP CHILDREN OUT OF REACH*.

4. Let the Psithemius radiate UV-light through the fluid condenser for a desired period of time, then turn the Psithemius off using its main power switch at the rear left of the device while avoiding looking into the ultraviolet light

5. Proceed with the scrying operation

### IV. Wishing Machine / Sigil Activator

1. If you have the Sublunar Psionics Ingress Plate, you can use it in combination with the Psithemius as a "wishing machine" or sigil activator.

2. Optionally place a single pointed quartz crystal into the center of the triangle for improved amplification. Press button B to initiate a clearing routine of the crystal. Keep away from the UVA light and come back when the UV-LEDs have turned off after 60 seconds.

*CAUTION:*

* The device has three built in 385nm UV-A LEDs that are quite intense (120mW) and can be harmful to eyes and skin.
* Follow the instructions carefully!
* Do Not look directly into UV light. This can be harmful to the human body especially to the eyes and skin, even for brief period due to the intense UV light.
* If viewing the UV light is necessary, please use UV filtered glasses to avoid damage by the UV light.
* Avoid direct eye and skin exposure to the UV light.
* *KEEP CHILDREN OUT OF REACH*.

3. If your goal(s) correspond with a planetary energy, feel free to choose an appropriate color using momentary presses of button A

4. Alternatively you may also employ the fundamental powers of contingency and randomness to amplify your intent by pressing and holding button A until the LED will flash in random colors.  

5. Place one or more slips of paper with your well formulated or sigilized goal(s) onto the Ingress Plate. Do not use the Universal Lamen cover disk.

6. Connect the Ingress Plate into the 3.5mm 1/8" mini jack at the rear end of the Psithemius using a male to male 3.5mm 1/8" mini jack cable.

7. It is recommended to connect a wire to the M2.5 tap hole earth connector located in the middle between the Barrel jack and 3.5mm 1/8" at the rear end of the Psithemius. The other end of the wire should be physically connected to the earth, either by using a wire and a pole or by connecting it to the pipe of a radiator.

8. Press button C to activate the internal amplification circuit. The psionic signal coming from the Ingress Plate is turned into an electromagnetic field radiating out of the clockwise spiral in the center of the triangle. 

9. Use the thumb wheel at the front left of the device to adjust the amplification gain. Turn it to the left (clockwise) for a lesser (down to 20fold) amplification of the signal. Or turn it to the right (counterclockwise) for a stronger (up to 200fold).

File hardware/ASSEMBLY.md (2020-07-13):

- [Assembling the DIY Psithemius](#assembling-the-diy-psithemius)
  * [1. Resistors](#1-resistors)
  * [2. Integrated Circuit Chips](#2-integrated-circuit-chips)
  * [3. Power Switch & Special Resistors](#3-power-switch---special-resistors)
  * [4. Unpolarized Capacitors](#4-unpolarized-capacitors)
  * [5. Rear Connectors](#5-rear-connectors)
  * [6. Polarized Capacitors](#6-polarized-capacitors)
  * [7. UV LEDs](#7-uv-leds)
  * [8. Buttons & Extra Connectors](#8-buttons---extra-connectors)
  * [9. Mechanical Assembly](#9-mechanical-assembly)
  * [10. Finalizing](#10-finalizing)
- [Troubleshooting](#troubleshooting)

# Assembling the DIY Psithemius

I usually start with the lowest profile components and work up to the highest. This guide follows my order of assembly.

## 1. Resistors

Identify the carbon film resistors using the color coding and stick them through the footprints of the PCB.

| Reference | Quantity | Value | Color Code | 
|---|---|---|---|
|R1-R4, R7  | 5| 10KΩ|[brown, black, orange, gold](components/10k-ohm-resistor-color-code.jpg)|
|R5 | 1| 10Ω|[brown, black, black, gold](components/10-ohm-resistor-color-code.jpg)|
|R6, R11, R15| 3| 180Ω|[brown, grey, brown, gold](components/180-ohm-resistor-color-code.jpg)|
|R8-R10 | 3| 680Ω|[blue, grey, brown, gold](components/680-ohm-resistor-color-code.jpg)|
|R12-R14 | 3| 330Ω|[orange, orange, brown, gold](components/330-ohm-resistor-color-code.jpg)|

Stick them in from the top of the PCB, turn the PCB around and lay it flat on a table. Solder the resistor leads to the through-holes and clip the excess off.

R16 is a large wirewound resistor. Do that one at [Step 4](#4-power-switch---special-resistors).

## 2. Integrated Circuit Chips

Now, identify the four different ICs and stick them into their footprints from the top. For each IC make sure the tiny dot on the chip marking pin 1 is placed into the square plated through-hole marking pin 1. Be careful to not push too hard and avoid bending their legs. Turn the PCB around and lay it flat on a table. Solder all legs.

| Reference | Color | No. legs |
|---|---|---|
|U1 | black | 14|
|U2 | white | 8|
|U3 | white | 4|
|U4 | black | 8|

## 3. Power Switch & Special Resistors

Now proceed with the 6 legged power switch S1. Make sure the switch points outward away from the PCB disk. Do the same with the three legged variable resistor VR1.

Now solder the wire wound resistor R16. It's a bit tricky to get it solidly fixed due to the thick leads and large through-holes. Use more solder than with the other parts. Clip of the excess leads when cooled down.

## 4. Unpolarized Capacitors

The next higher components are the unpolarized radial leaded multilayer ceramic capacitors. 

They are yellow andf have two equally long legs. There are three tiny ones (0.1uF) and one a bit bigger one (1uF).

Again, stick them in from the top of the PCB, turn the PCB around and lay it flat on a table. Solder the capacitor leads to the through-holes and clip the excess off.

Revision 11 of the Psithemius has three additional capacitor footprints C7, C8, C9 marked on the PCB. Just ignore them. They will remain empty.

## 5. Rear Connectors

Proceed soldering the barrel jack power connector. Revision 11 of the PCBs have a tiny error and the tiny plastic cube that sticks out of the bottom of this component does not have a matching hole in the PCB. In order to make it fit the footprint you need to cut this tiny piece of plastic off with an excacto knife or simply melt it with your hot soldering iron so the bottom plastic surface of the component is flat. Revision 12 of the PCB does not require this fix.

Proceed with the 3.5mm 1/8" stereo audio mini jack. The revision 11 footprint of this component has too many through-holes. Just solder the ones that have legs sticking through and ignore the others.

Now solder the full metal grounding connector in between the audio jack and power jack. I usually place it into the through-holes, the hole pointing outwards away from the PCB, turn the PCB around and lay it flat on the table, then I make sure the component is parallel to the PCB and table and I use quite a lot of solder to fix it to the holes.

## 6. Polarized Capacitors

The polarized capacitors need to be placed onto their circular "half-moon" type footprints. Make sure the longer leg (anode) of each pol. capacitor goes into the squarish through-hole on the dark half of the footprint with the little + symbol next to it. The greyish area of the pol. capacitor should point to the bright side of the "half-moon" footprint. Push them all the way down onto the PCB, otherwise they will be too high.

## 7. UV LEDs

Now assemble the 3 UV LEDs by placing them into their footprints. Caution! The footprint logic for diodes is opposite from the polarized capacitors. Here, the shorter leg (cathode) of each LED needs to go into the square through-hole near the flattened part of the footprint.

ATTENTION: make sure to not place them all the way into the footprint but leave a few millimeters space. They need to be bent in a 45° angle towards the center of the triangle on the PCB after they have been soldered. Only stick the legs through so the tiny "stoppers" on the legs will still be above the top layer of the PCB. I usually stick the LED into the PCB, then poke the plastic rod of a q-tip through its legs between the "bulb" and the PCB. Turn around and solder, remove the q-tips and finally bend the "bulbs" so they point towards the center of the triangle.

## 8. Buttons & Extra Connectors

I usually finish with the three push-buttons. Carefully click them into their footprints and solder them. The three black caps click neatly on top of the switches.

If you want to be able to upgrade the firmware of the Psithemius or code your own firmware, you need to solder the 6 pin AVR connector to the front side of the PCB.

There will be a DIY battery add-on for the Psithemius. In order to connect it, there is already a footprint for the white horizontal battery connector behind the barrel jack power connector. ATTENTION: It needs to be soldered upside down! Stick it through the footprint from the bottom of the PCB and solder the four pins from the top.

## 9. Mechanical Assembly

Put the four 25mm M2.5 screws into the four holes of the top-plate of the Psithemius with the magical symbols. Carefully flip it upside down, so the tips of the screws are pointint up.

Place the four 9mm long black distance bolts onto the screws.

Now carefully stick the fully assembled PCB upside down onto the four screws until it firmly rests on the distance bolts. Make sure the three buttons go through the openings of the top-plate.

Place the four 7mm long black distance bolts onto the screws sticking through the PCB.

Now place the glossy black plexiglass disk onto the screws until it firmly rests on the distance bolts.

Finally place the four washers and nuts and tighten all screws. Stick the four adhesive rubber bumpers next to the nuts, so the device has feet.

## 10. Finalizing

Turn the assembled Psithemius around and make sure everything fits tightly. Plug the USB power cable into the barrel jack and try out all the buttons.

# Troubleshooting

* None of the buttons do anything!
  + Check the solder contacts of the barrel jack and the power switch

* The Psithemius blinks and occasionally turns off!
  + Check the solder contacts of the barrel jack and make sure the polarized capacitor behind the audio jack is placed in the correct direction.

* The UV LEDs don't work!
  + You probably soldered the LEDs in the wrong direction.

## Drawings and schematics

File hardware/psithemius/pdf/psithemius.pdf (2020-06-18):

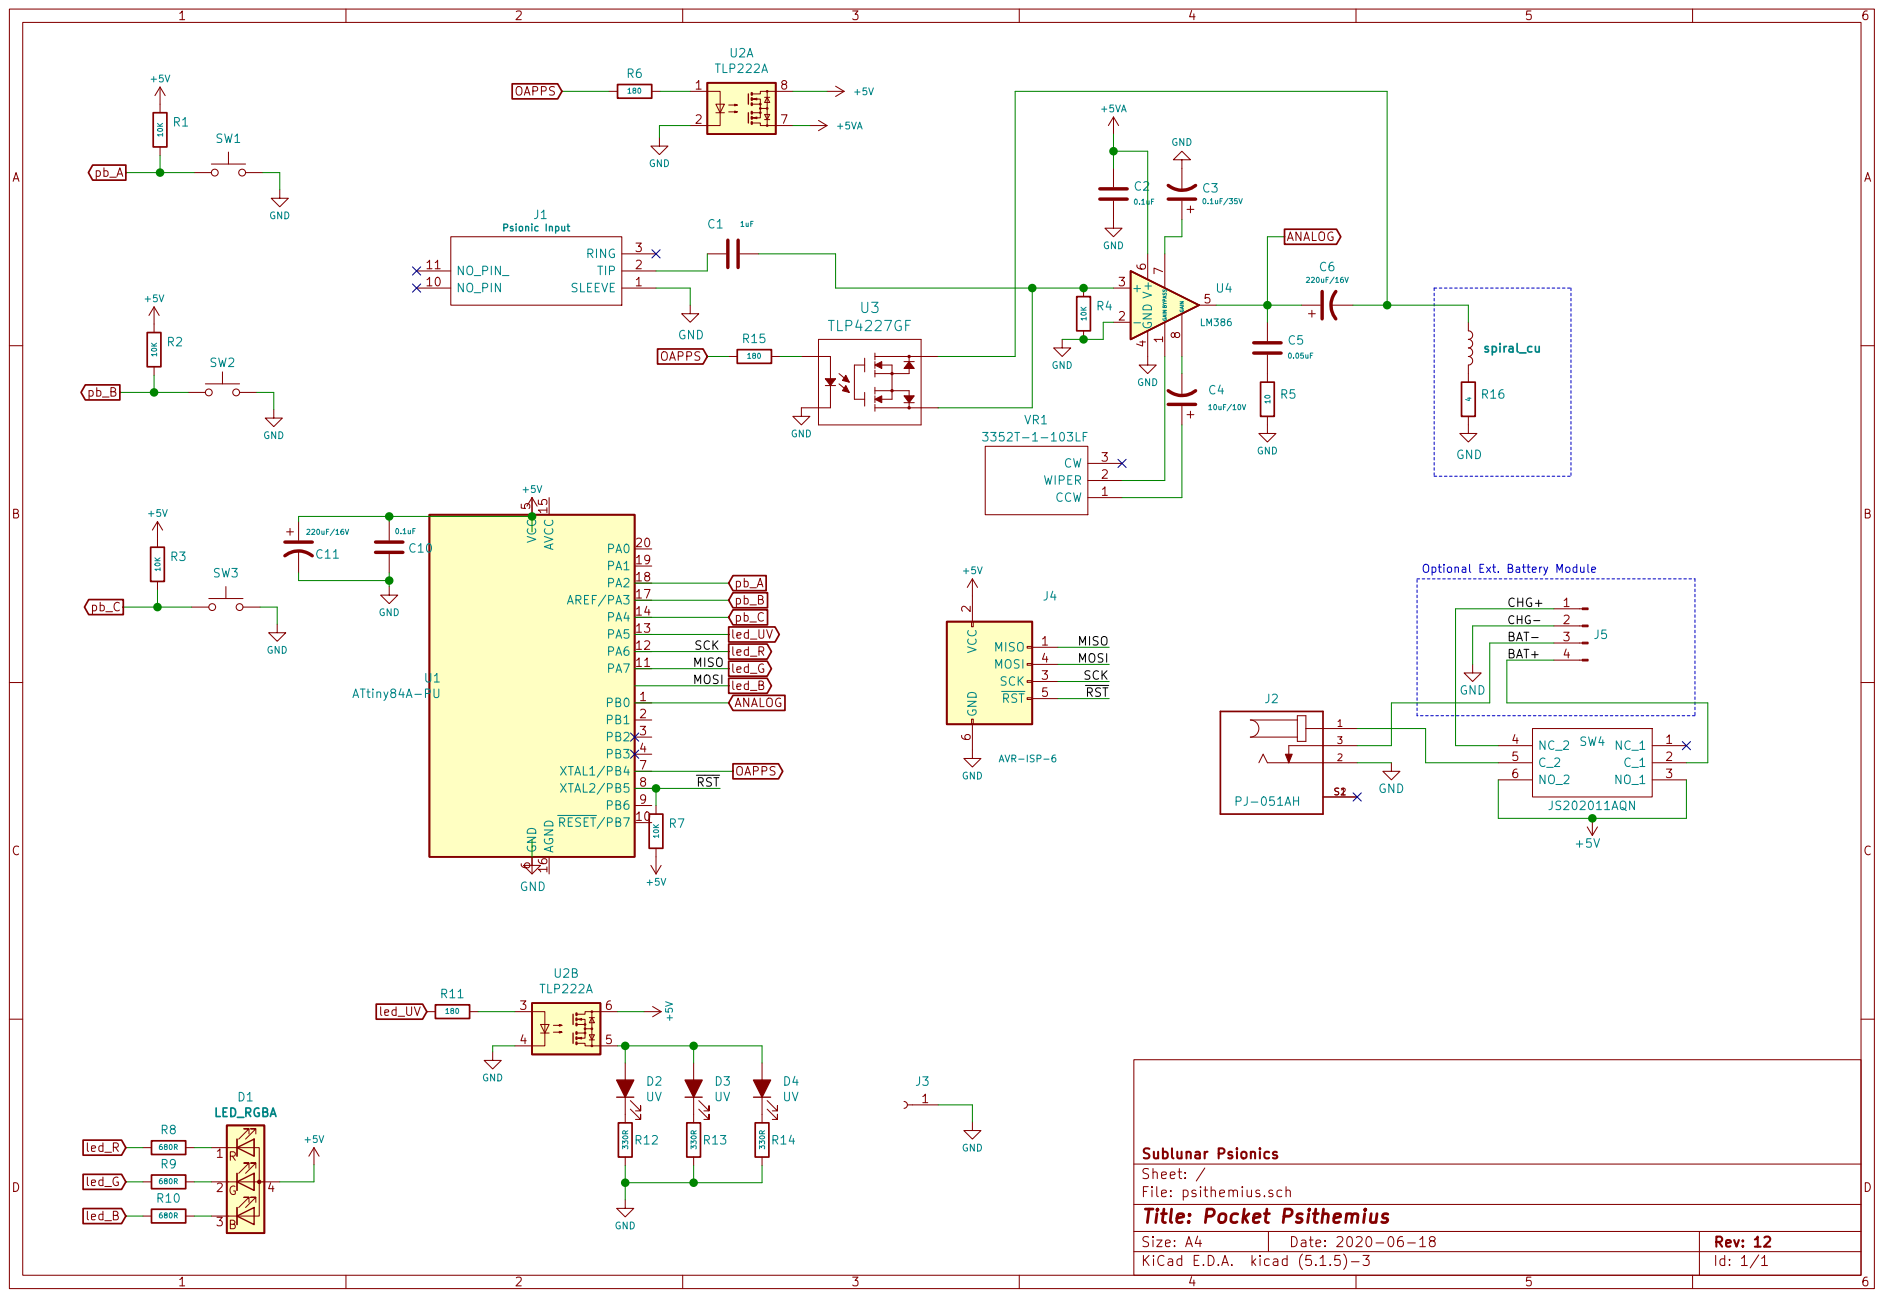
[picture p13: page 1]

2 SCK 3 MOSI 4 RST 5 GND

File: psithemius.sch Sheet: / Sublunar Psionics

Id: 1/1 Title: Pocket Psithemius

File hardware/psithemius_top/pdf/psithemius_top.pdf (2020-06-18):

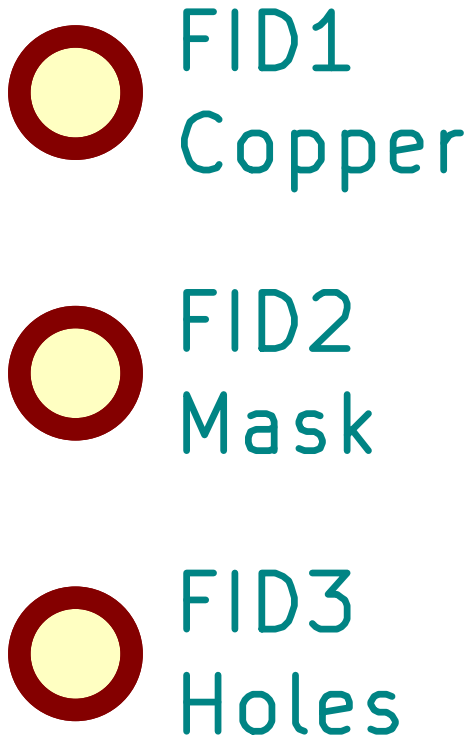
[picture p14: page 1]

D Date: 2020-06-18 KiCad E.D.A. kicad (5.1.5)-3
File: psithemius_top.sch Sheet: / Sublunar Psionics

Id: 1/1 Title: Pocket Psithemius Top

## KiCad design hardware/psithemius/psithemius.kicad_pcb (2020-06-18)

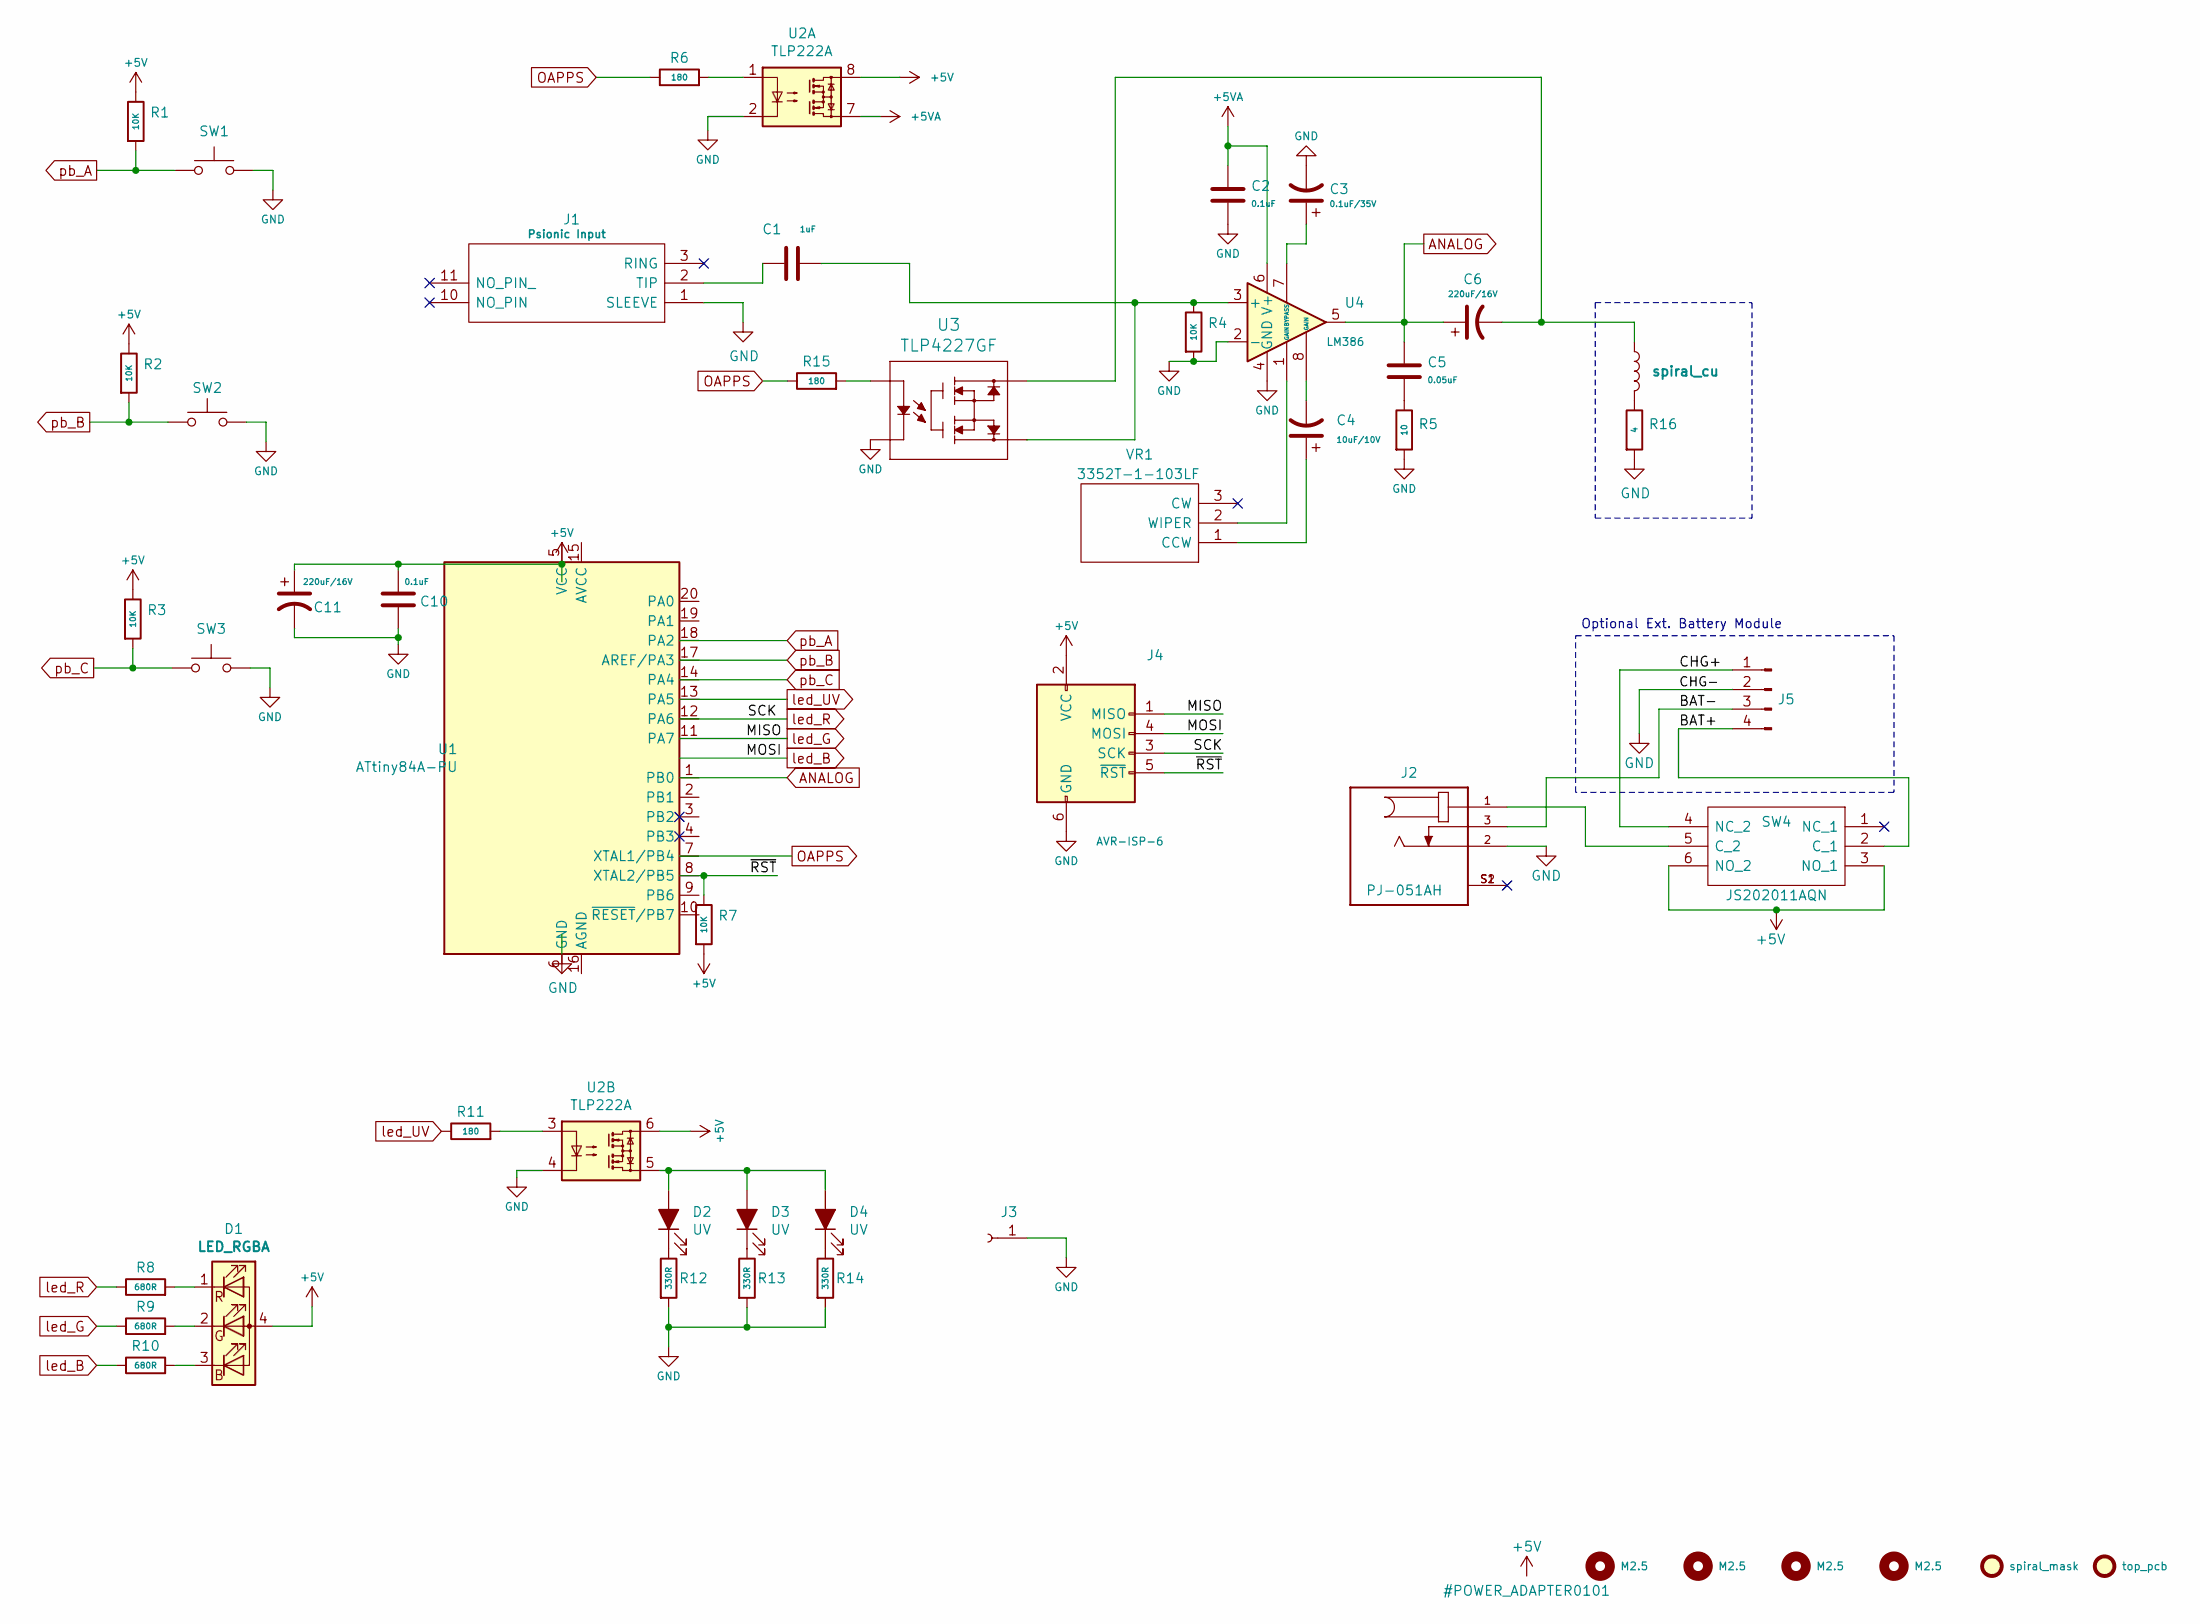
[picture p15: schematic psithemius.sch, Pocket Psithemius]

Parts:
C1: 1uF; C_Disc_D5.1mm_W3.2mm_P5.00mm; Part Number K105Z20Y5VF5TH5; Digi-Key BC1168CT-ND
C2, C10: 0.1uF; C_Disc_D4.7mm_W2.5mm_P5.00mm; Part Number K104K15X7RF5TH5; Digi-Key BC1101CT-ND
C3: 0.1uF/35V; CP_Radial_D4.0mm_P1.50mm; Part Number UMA1H0R1MCD2TP; Digi-Key 493-10420-3-ND
C4: 10uF/10V; CP_Radial_D4.0mm_P1.50mm; Part Number USV1C100MFD; Digi-Key 493-16020-ND
C5: 0.05uF; C_Disc_D4.7mm_W2.5mm_P5.00mm; Part Number 89350; Digi-Key 2368-89350-ND
C6: 220uF/16V; CP_Radial_D8.0mm_P5.00mm; Part Number UVR1C221MED1TA; Digi-Key 493-6096-1-ND
C11: 220uF/16V; CP_Radial_D8.0mm_P5.00mm; Part Number USR1C221MDD; Digi-Key 493-15996-ND
D1: LED_RGBA; WurthElektronik_156125M173000; Part Number 156125M173000; Digi-Key 732-11426-1-ND
D2, D3, D4: UV; LED_D5.0mm_Clear; Part Number VAOL-5GUV8T4; Digi-Key VAOL-5GUV8T4-ND
FID1: spiral_mask; LOGOТ_MASK; Part Number - - -; Digi-Key - - -
FID2: top_pcb; trithemius_top; Part Number - - -; Digi-Key - - -
FID3: spiral_cu; LOGO1; Part Number - - -; Digi-Key - - -
H1, H2, H3, H4: M2.5; RAF_M1257-2545-AL
J1: Psionic Input; SJ13523N; Part Number SJ1-3523N; Digi-Key CP1-3523N-ND
J2: PJ-051AH; CUI_PJ-051AH; Part Number PJ-051AH; Digi-Key CP-051AH-ND
J3: 7761; Earth; Part Number 7761; Digi-Key 36-7761-ND
J4: AVR-ISP-6; IDC-Header_2x03_P2.54mm_Horizontal; Part Number 61200621721; Digi-Key 732-5404-ND
J5: Internal Power; JST_PH_S4B-PH-K_1x04_P2.00mm_Horizontal; Part Number S4B-PH-K-S(LF)(SN); Digi-Key 455-1721-ND
R1, R2, R3, R4, R7: 10K; R_Axial_DIN0204_L3.6mm_D1.6mm_P7.62mm_Horizontal; Part Number CF18JT10K0; Digi-Key CF18JT10K0CT-ND
R5: 10; R_Axial_DIN0204_L3.6mm_D1.6mm_P7.62mm_Horizontal; Part Number CF18JT10R0; Digi-Key CF18JT10R0CT-ND
R6, R11, R15: 180; R_Axial_DIN0204_L3.6mm_D1.6mm_P7.62mm_Horizontal; Part Number CF18JT180R; Digi-Key CF18JT180RCT-ND
R8, R9, R10: 680R; R_Axial_DIN0204_L3.6mm_D1.6mm_P7.62mm_Horizontal; Part Number CF18JT680R; Digi-Key CF18JT680RCT-ND
R12, R13, R14: 330R; R_Axial_DIN0204_L3.6mm_D1.6mm_P7.62mm_Horizontal; Part Number CF18JT330R; Digi-Key CF18JT330RCT-ND
R16: 4; R_Axial_DIN0614_L14.3mm_D5.7mm_P20.32mm_Horizontal; Part Number WW1AFT4R00; Digi-Key WW1AFT4R00-ND
SW1, SW2, SW3: B3F-4050; SW_Tactile_SPST-NO_Omron_B3F-40xx; Part Number B3F-4050; Digi-Key SW413-ND
SW4: JS202011AQN; Mouser Part Number 611-JS202011AQN
U1: ATtiny84A-PU; DIP-14_W7.62mm; Part Number ATTINY84-20PU; Digi-Key ATTINY84-20PU-ND
U2: TLP222A; DIP-8_W7.62mm; Part Number TLP222A-2(F); Digi-Key TLP222A-2F-ND
U3: TLP4227GF; DIP-4_W7.62mm; Part Number TLP4227GF; Digi-Key TLP4227GF-ND
U4: LM386; DIP-8_W7.62mm; Part Number LM386MX-1/NOPB; Digi-Key 296-44414-5-ND
VR1: 3352T-1-103LF; 3352T1103LF; Mouser Part Number 652-3352T-1-103LF

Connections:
+5V: C10.2, C11.1, D1.4 (A), J4.2 (VCC), R1.1, R2.1, R3.1, R7.2, SW4.3 (NO_1), SW4.6 (NO_2), U2.6, U2.8
+5VA: C2.1, U2.7, U4.6 (V+)
/BAT+: J5.4, SW4.2 (C_1)
/BAT-: J2.3, J5.3
/CHG+: J5.1, SW4.4 (NC_2)
/~RST: J4.5 (~RST), R7.1
ANALOG: C5.1, C6.1, U4.5
GND: C2.2, C3.2, C10.1, C11.2, J1.1 (SLEEVE), J2.2, J3.1, J4.6 (GND), J5.2, R4.2, R5.2, R12.2, R13.2, R14.2, R16.2, SW1.2, SW2.2, SW3.2, U2.2, U2.4, U3.2, U4.2 (-), U4.4 (GND)
unnamed: C1.1, R4.1, U3.3 (DRAIN), U4.3 (+)
unnamed: C1.2, J1.2 (TIP)
unnamed: C3.1, U4.7 (BYPASS)
unnamed: C4.1, VR1.1 (CCW)
unnamed: C4.2, U4.8 (GAIN)
unnamed: C5.2, R5.1
unnamed: C6.2, FID3.1, U3.4 (DRAIN)
unnamed: D1.1 (RK), R8.2
unnamed: D1.2 (GK), R9.2
unnamed: D1.3 (BK), R10.2
unnamed: D2.1 (K), R12.1
unnamed: D2.2 (A), D3.2 (A), D4.2 (A), U2.5
unnamed: D3.1 (K), R13.1
unnamed: D4.1 (K), R14.1
unnamed: FID3.2, R16.1
unnamed: J2.1, SW4.5 (C_2)
unnamed: J2.S1 (SHIELD), J2.S2 (SHIELD)
unnamed: R6.2, U2.1
unnamed: R11.2, U2.3
unnamed: R15.2, U3.1
unnamed: U4.1 (GAIN), VR1.2 (WIPER)
OAPPS: R6.1, R15.1
led_B: J4.4 (MOSI), R10.1
led_G: J4.1 (MISO), R9.1
led_R: J4.3 (SCK), R8.1
led_UV: R11.1
pb_A: R1.2, SW1.1
pb_B: R2.2, SW2.1
pb_C: R3.2, SW3.1

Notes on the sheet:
Optional Ext. Battery Module

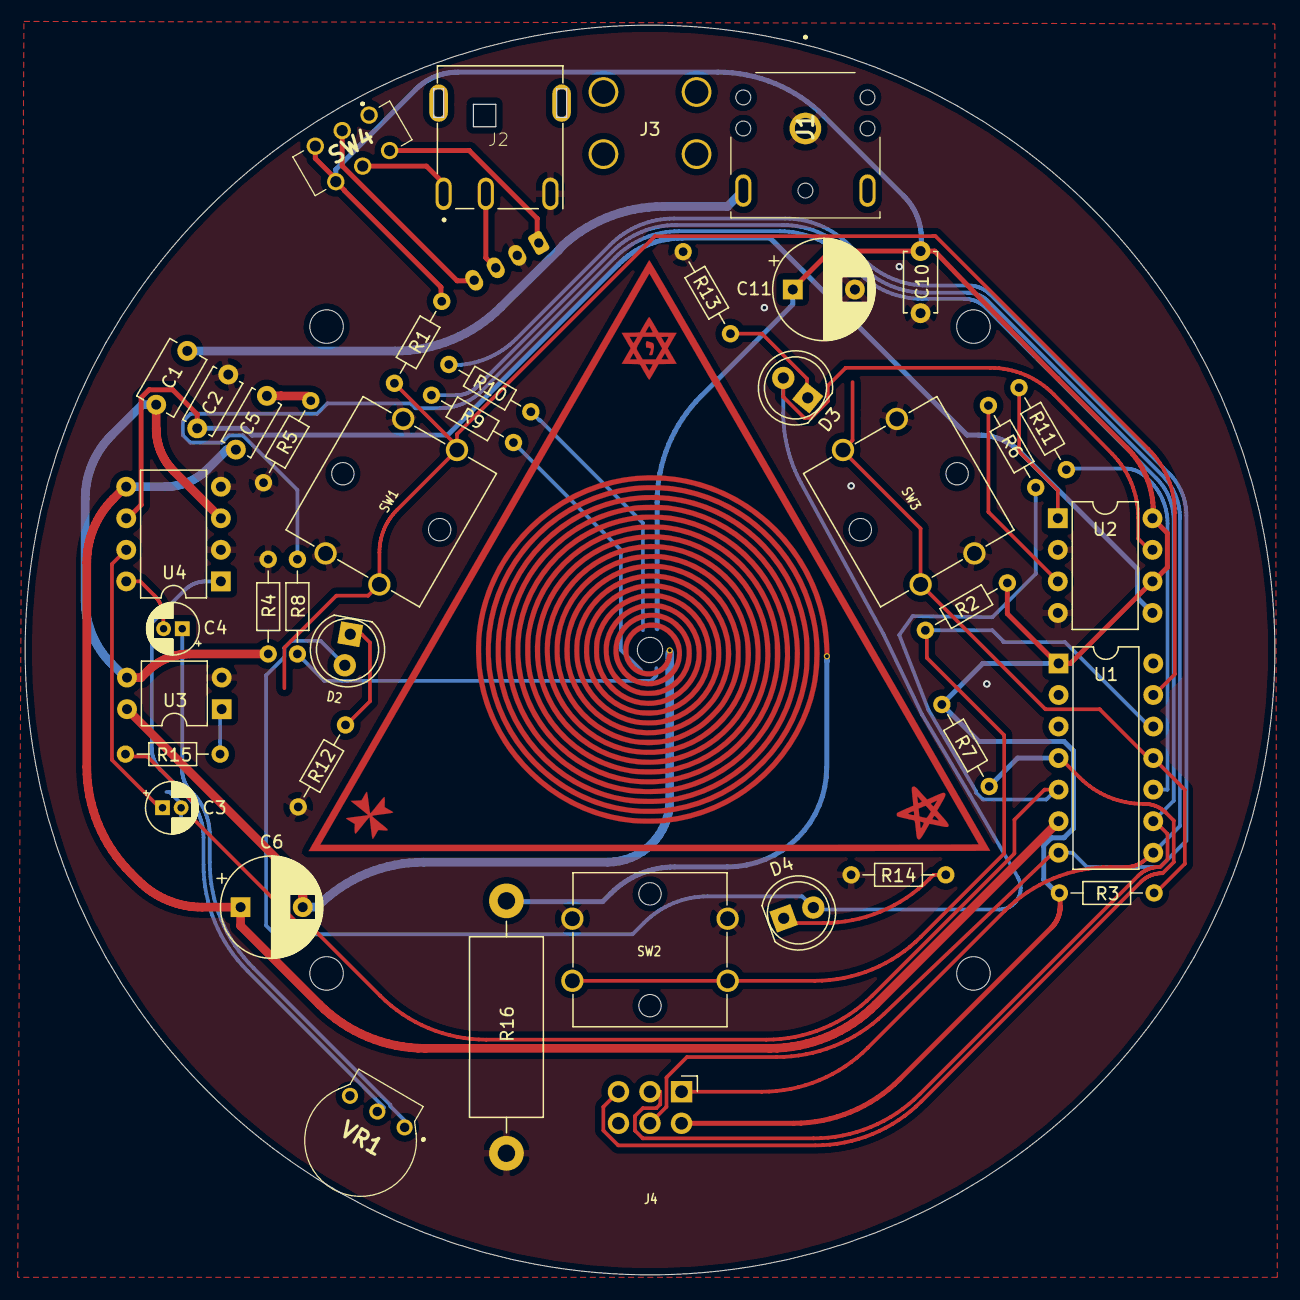
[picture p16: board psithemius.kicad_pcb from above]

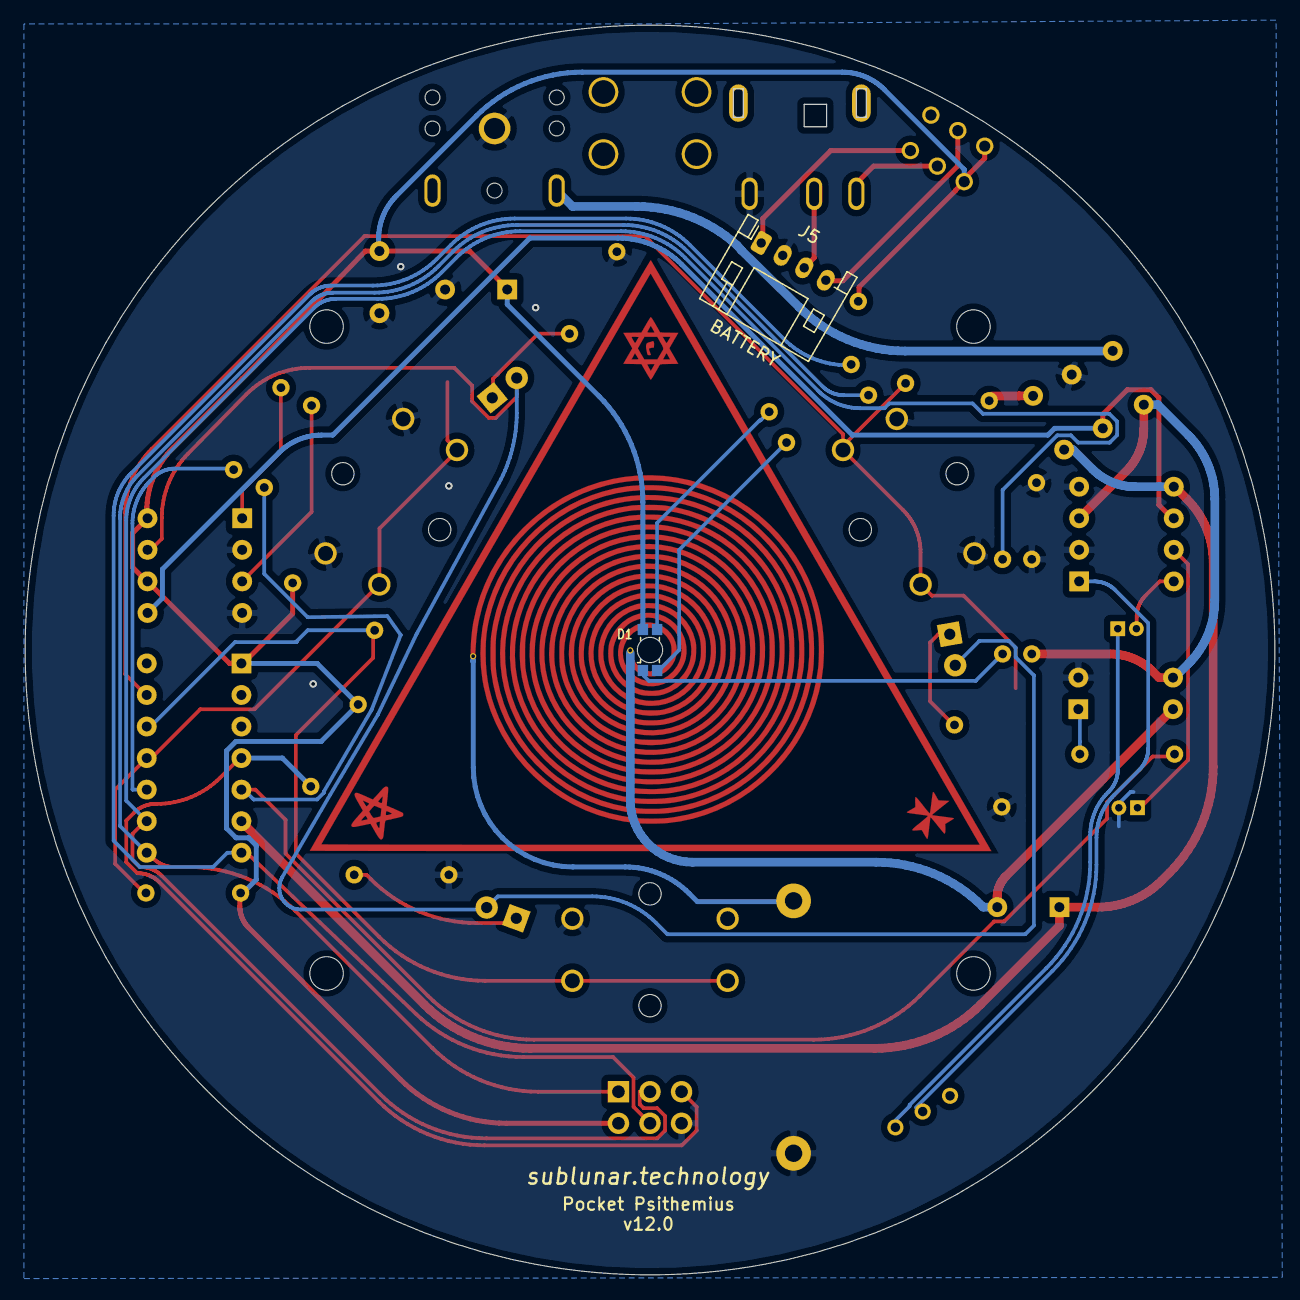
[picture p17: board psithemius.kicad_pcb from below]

Board: 2 copper layers, 100.6 x 100.6 mm, 49 parts (2 on the bottom side), 36 nets.

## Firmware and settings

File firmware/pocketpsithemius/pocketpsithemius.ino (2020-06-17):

/*Copyright (c) 2020 Sublunar Psionics

Special Thanks to Slavko Andrejevic for providing the main framework of this
firmware and for technical support.

---- MIT License ----

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
*/

#include <OneButton.h>

#define btnA            0      // PA0 / Button A:
#define btnB            2      // PA1 / Button B:
#define btnC            1      // PA2 / Button C:
#define led_R           4      // PA4 / RED LED
#define led_G           5      // PA5 / GREEN LED
#define led_B           6      // PA6 / BLUE LED
#define uv_LED          3      // PA3 / UV LED
#define OPAMP           8      // PB2 / turns on the Op Amp circuit
#define ANALOG          7      // PA7 / Get analog
#define REG1            9      // PB1 / unconnected
#define REG2           10      // PB0 / unconnected

#define ON              HIGH
#define OFF             LOW

//---- BUTTONS ----

byte counterA         = 0;     // count push btnA:
byte counterB         = 0;     // count push btnB:
byte counterC         = 0;     // count push btnC:
bool enabled_btnAC    = true;  // Button A + C enabled or not
bool enabled_btnB     = true;  // Button B enabled or not

OneButton buttonA(btnA, true); // Button A setup
OneButton buttonB(btnB, true); // Button B setup
OneButton buttonC(btnC, true); // Button C setup

//---- LEDS ----

bool enabled_LED      = false; //turn on a tricolor LED
bool usePWM           = false; //use softPWM for more nuanced colors
bool disco            = false; // random colors

//---- TIMER ----

bool countDelay       = false; //are we counting ticks to time out the UV LEDs?
uint32_t oldTime      = millis();

//---- COLOR ----

struct COLOR { // Creating structure for colors
  byte r;
  byte g;
  byte b;
};
COLOR selectedColor   = { 0, 0, 0 };

//---- PLANETARY COLORS ----

COLOR white           = { 255 , 255 , 255 }; // Moon correspondence
COLOR orange          = { 255 , 128 ,   0 }; // Mercury correspondence
COLOR green           = {   0 , 255 ,   0 }; // Venus correspondence
COLOR yellow          = { 255 , 255 ,   0 }; // Sol correspondence
COLOR red             = { 255 ,   0 ,   0 }; // Mars correspondence
COLOR blue            = {   0 , 128 , 255 }; // Jupiter correspondence
COLOR purple          = { 128 ,   0 , 128 }; // Jupiter/Moon correspondence
COLOR indigo          = { 111 ,   0 , 255 }; // Saturn correspondence
COLOR grey            = {  40 ,  40 ,  40 }; // Saturn correspondence

//---- DEVICE SETUP ----
void setup() {

  // BUTTONS
  buttonA.attachClick(cycleColors);
  buttonA.attachLongPressStart(discoStart);
  buttonB.attachClick(ultraviolet);
  buttonB.attachLongPressStart(uvForever);
  buttonC.attachClick(opAmp);

  // LEDS
  pinMode(led_B, OUTPUT);
  pinMode(led_G, OUTPUT);
  pinMode(led_R, OUTPUT);
  offLeds();

  // UV LED
  pinMode(uv_LED, OUTPUT);
  digitalWrite(uv_LED, OFF);

  // OP AMP
  //pinMode(ANALOG, INPUT);
  pinMode(OPAMP, OUTPUT);
  digitalWrite(OPAMP, OFF);

}

//---- DEVICE LOOP ----
void loop() {

  buttonA.tick();
  buttonB.tick();
  buttonC.tick();
  showColor();

  // If enabled, turns UV LED off after 1min
  if ( countDelay == true && ((millis()-oldTime) > 60000)) {
    //Turn the UV LED off
    enabled_btnAC = true;
    digitalWrite(uv_LED, OFF);
    counterB = 0;
    countDelay = false;
  }

  if ( disco == true ) {
    enabled_LED = true;
    usePWM = false;
    selectedColor.r = rng();
    selectedColor.g = rng();
    selectedColor.b = rng();
    //digitalWrite(uv_LED, bitRead(rng(), 0));
    showColor();
    delay(rng());
  }
  
}

//---- FUNCTIONS ----

// turn all LEDs off
void offLeds() {
  analogWrite(led_R, 255);
  analogWrite(led_B, 255);
  analogWrite(led_G, 255);
}

// set a color
void setColor(COLOR paint, bool full = true) {
  //tricolor LED color
  selectedColor.r = paint.r;
  selectedColor.b = paint.b;
  selectedColor.g = paint.g;
  showColor();
}

// show the color or turn off
void showColor() { // 100% of color
  if (enabled_LED == true) {
      softPWM(led_R, selectedColor.r, 1);
      softPWM(led_B, selectedColor.b, 1);
      softPWM(led_G, selectedColor.g, 1);
  } else {
    offLeds();
  }
}

void discoStart() {
  if ( disco == true ) {
    disco = false;
    enabled_LED = false;
    //digitalWrite(uv_LED, OFF);
    counterA = 0;
  }
  else disco = true;
}

// used for button A to cycle through the colors
void cycleColors() {
  if ( disco == true) discoStart();
  if (enabled_btnAC == true) {
    counterA++;
    switch (counterA) {
      case 1:
        enabled_LED = true;
        setColor(white, true);
        break;
      case 2:
        usePWM = true;
        setColor(orange, true);
        break;
      case 3:
        usePWM = false;
        setColor(green, true);
        break;
      case 4:
        setColor(yellow, true);
        break;
      case 5:
        setColor(red, true);
        break;
      case 6:
        setColor(blue, true);
        break;
      case 7:
        usePWM = true;
        setColor(purple, true);
        break;
      case 8:
        setColor(indigo, true);
        break;
      case 9:
        setColor(grey, true);
        break;
      case 10:
        enabled_LED = false;
        counterA = 0;//TURN OFF
        break;
    }
  }
}

// used for button B to toggle the UV LEDs
void ultraviolet() {
  counterA = 0;
  if ( disco == true) discoStart();
  if (enabled_btnB == true) {
    counterB++;
    switch (counterB) {
      case 1:
        blinker(led_B, 500, 5);
        enabled_LED = false;
        enabled_btnAC = false;
        digitalWrite(uv_LED, ON);
        if ( countDelay == false ) {
          oldTime    = millis();
        }
        countDelay = true; // turn on delay counter in loop()
        break;
      case 2:
        enabled_btnAC = true;
        digitalWrite(uv_LED, OFF);
        counterB = 0;
        break;
    }
  }
}

// disable all buttons and keep UV light running forever
void uvForever() {
  blinker(led_B, 500, 5);
  blinker(led_B, 50, 10);
  enabled_btnB = false;
  enabled_btnAC = false;
  countDelay = false;
  digitalWrite(uv_LED, ON);
}

// used for button C to toggle the OP Amp
void opAmp() {
  if (enabled_btnAC == true) {
    counterC++;
    switch (counterC) {
      case 1:
        blinker(led_G, 50, 2);
        digitalWrite(OPAMP, ON);
        break;
      case 2:
        blinker(led_R, 50, 2);
        digitalWrite(OPAMP, OFF);
        counterC = 0;
        break;
    }
  }
}

// helper to blink a color
void blinker(byte pin, int len, byte rep) {
  byte counter = 1;
  while (counter <= rep) {
    analogWrite(pin, 0);
    delay(len);
    offLeds();
    delay(len);
    counter++;
  }
}

// software PWM function that fakes analog output
void softPWM(byte pin, byte freq, byte sp) {
  byte delay1 = 255 - freq;
  if (usePWM == true) {
    while (sp > 0) {
      digitalWrite(pin, LOW); //on
      delayMicroseconds(freq);
      digitalWrite(pin, HIGH); //off
      delayMicroseconds(delay1);
      sp--;
    }
  } else {
    analogWrite(pin, 255 - freq);
  }
}

byte rng() {
  int raw0, raw1;
  byte b0, b1, x, col, twoBytes[2], result;
  col = 0;
  while ( col <= 1 ) {
    raw0 = analogRead(REG1);
    raw1 = analogRead(REG2);
    b0 = lowByte(raw0);
    b1 = lowByte(raw1);
    x = b0 ^ b1;
    twoBytes[col] = x;
    col++;
  }
  result = (twoBytes[0]<<4)+twoBytes[1];
  return result;
}

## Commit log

2020-06-18 added KiCAD Files and MANUAL.md
    [CUI_DEVICES_PJ-051AH.step, RAF_M1257-2545-AL.step, SW_Tactile_SPST-NO_Omron_B3F-40xx.step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]
2020-06-21 added BOM.csv
    [BOM.csv]
2020-06-21 added ASSEMBLY instructions
    [BOM.csv]
2020-06-21 added pdfs and jpgs
    [BOM.csv, psithemius.sch]
2020-06-29 SW4 is S1
    [BOM.csv]
2020-07-13 changed assembly order
